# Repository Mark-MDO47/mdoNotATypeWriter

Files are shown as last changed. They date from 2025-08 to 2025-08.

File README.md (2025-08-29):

# mdo NotATypeWriter
My version of the fantastic Adafruit Learning project "Not A Typewriter".

The original is here:
- https://learn.adafruit.com/not-a-typewriter
- Ruiz Brothers and Liz Clark

I am happy to provide Attribution to Adafruit and to the Ruiz Brothers (3D design) and to Liz Clark (author of the code) !

| Original | Mine |
| --- | --- |
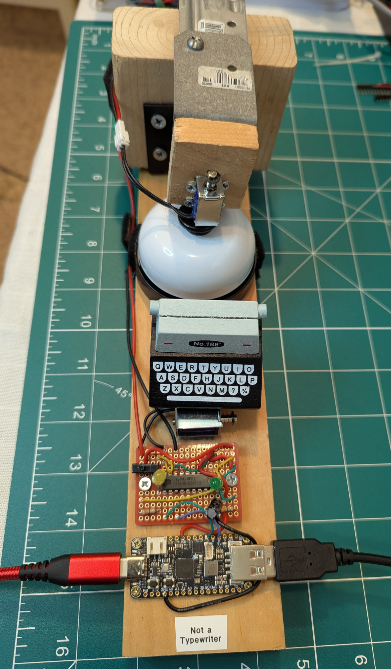
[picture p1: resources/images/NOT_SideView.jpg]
MDO Not A TypewriterFront View
| Original Adafruit Learning Not A Typewriter |  |

**Table Of Contents**
* [Top](#mdo-notatypewriter "Top")
* [Introduction](#introduction "Introduction")
* [Differences from Original Adafruit Learning Not A Typewriter](#differences-from-original-adafruit-learning-not-a-typewriter "Differences from Original Adafruit Learning Not A Typewriter")
* [RP2040 and Dual USB](#rp2040-and-dual-usb "RP2040 and Dual USB")
  * [CircuitPython USB Keyboard Documentation](#circuitpython-usb-keyboard-documentation "CircuitPython USB Keyboard Documentation")
  * [Arduino USB Keyboard Documentation](#arduino-usb-keyboard-documentation "Arduino USB Keyboard Documentation")
* [The Code - Derived from Adafruit Learning](#the-code-\--derived-from-adafruit-learning "The Code - Derived from Adafruit Learning")
* [Schematic](#schematic "Schematic")
* [Assembly](#assembly "Assembly")
* [Parts List](#parts-list "Parts List")
* [License](#license "License")

## Introduction
[Top](#mdo-notatypewriter "Top")<br>
The "Not A Typewriter" project was so great I had to make a copy for myself.

Here is a video of my version in action:
- https://youtube.com/shorts/a_9GTjH4s5s

## Differences from Original Adafruit Learning Not A Typewriter
[Top](#mdo-notatypewriter "Top")<br>
Some parts were unavailable at this time and others I chose to do in a slightly different manner.
- The I2C Solenoid Driver https://www.adafruit.com/product/6318 was not available at the time I ordered
  - ... so I replaced it with a non-I2C version https://www.adafruit.com/product/970
- The original project includes files for a beautiful 3D-printed typewriter/project-box
  - ... I chose to use a "dollhouse" typewriter https://www.amazon.com/dp/B0B86HYR6P and some cardboard boxes and scrap I had on hand

Here is an image of most of the cast of characters for this project.<br>
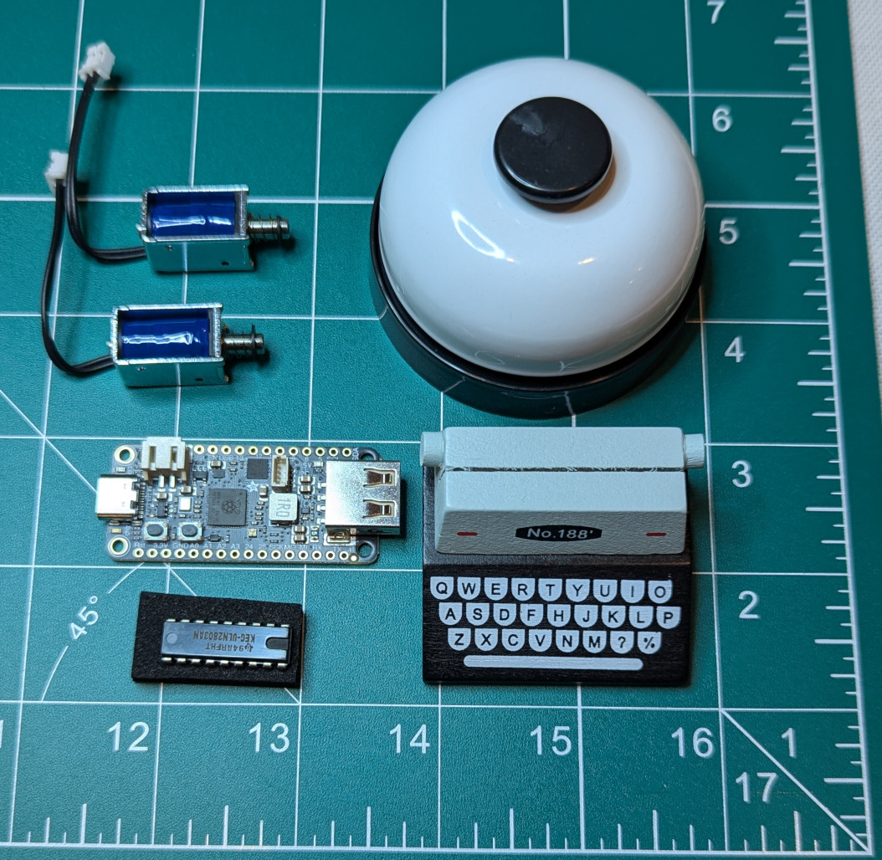
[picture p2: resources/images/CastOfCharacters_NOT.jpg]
My cast of characters for Not A Typewriter


## RP2040 and Dual USB
[Top](#mdo-notatypewriter "Top")<br>
The RP2040 is a new experience for me, as is the use of two USB interfaces. I gather that the "device" USB port is used to program the RP2040 and implemented by its native hardware USB facilities while the "host" USB port is implemented by software bit-banging, requiring one of the two M0 ARM cores of the RP2040 and both PIO peripherals. Still learning about this.
- https://www.adafruit.com/product/5723	https://learn.adafruit.com/adafruit-feather-rp2040-with-usb-type-a-host
- https://github.com/adafruit/Adafruit-Feather-RP2040-USB-Host-PCB/blob/main/Adafruit_Feather_RP2040_USB_Host_PrettyPins.pdf

This area contains information about the dual USB usage.
- https://github.com/adafruit/Adafruit_TinyUSB_Arduino/tree/master/examples/DualRole

Here is a work-in-progress list of things I need to keep in mind regarding this Dual USB technique and the RP2040.

For Arduino-style programming:
- RP2040: "pio_usb.h" must not be included, otherwise pio-usb will be used as host controller

For CircuitPython-style programming:
- nothing yet

### CircuitPython USB Keyboard Documentation
Some useful documentation for reading the keyboard data from the USB-A port
- https://learn.adafruit.com/using-a-keyboard-with-usb-host?view=all
- https://learn.adafruit.com/using-a-keyboard-with-usb-host/circuitpython
- https://learn.adafruit.com/adafruit-feather-rp2040-with-usb-type-a-host/usb-host-device-info-2

Some useful information for relaying keyboard data to the USB-C port and on into the PC
- https://docs.circuitpython.org/projects/hid/en/latest/
- https://docs.circuitpython.org/projects/hid/en/latest/api.html
- https://learn.adafruit.com/circuitpython-essentials/circuitpython-hid-keyboard-and-mouse
- https://learn.adafruit.com/adafruit-circuit-playground-express/circuitpython-hid-keyboard

### Arduino USB Keyboard Documentation
Some useful documentation for reading the keyboard data from the USB-A port
- https://learn.adafruit.com/using-a-keyboard-with-usb-host?view=all
- https://learn.adafruit.com/using-a-keyboard-with-usb-host/arduino
- https://learn.adafruit.com/adafruit-feather-rp2040-with-usb-type-a-host/arduino-ide-setup

## The Code - Derived from Adafruit Learning
[Top](#mdo-notatypewriter "Top")<br>
Here is a link to the area with my version of the code and a description of the changes I made.
- https://github.com/Mark-MDO47/mdoNotATypeWriter/blob/master/code/USB_Host_Not_A_Typewriter/README.md

## Schematic
[Top](#mdo-notatypewriter "Top")<br>
Below is the schematic for my version of the Not A Typewriter project.
- The main difference from the original version is the use of the ULN2803A chip instead of the I2C Solenoid Driver module
  - My favorite explanation of how to use ULN2803A are posts from pcmanbob starting at "Aug 15, 2023 9:13 am": https://forums.raspberrypi.com/viewtopic.php?t=354993
- I chose to use some regular GPIO pins to control the solenoids instead of the ones on the I2C connector
  - Saving the I2C connector in case I have another use for it
- I have some LEDs that flash when the solenoids activate and a switch that disables the solenoids but allows the LEDs to still work. This lets me type quietely when my family is asleep.

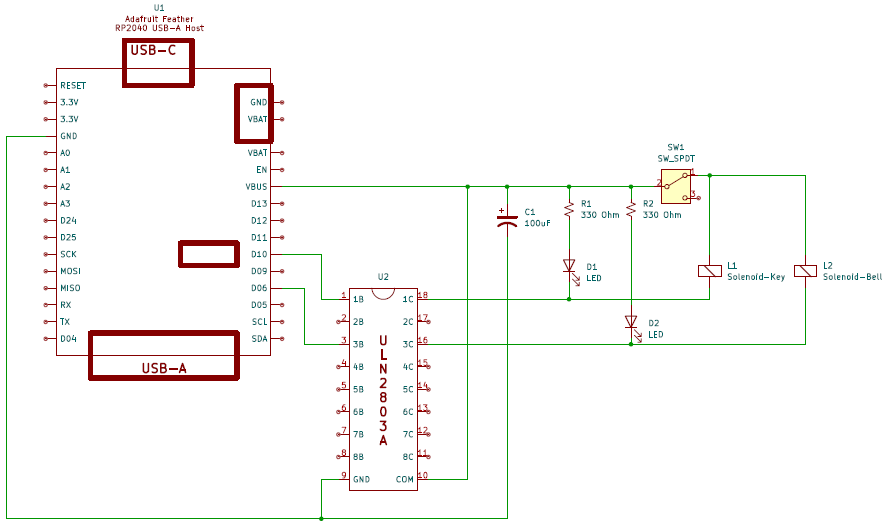
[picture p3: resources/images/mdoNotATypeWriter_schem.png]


## Assembly
[Top](#mdo-notatypewriter "Top")<br>
Below is a conceptual assembly diagram. Most of this is assembled on a perf stripboard; see below.<br>
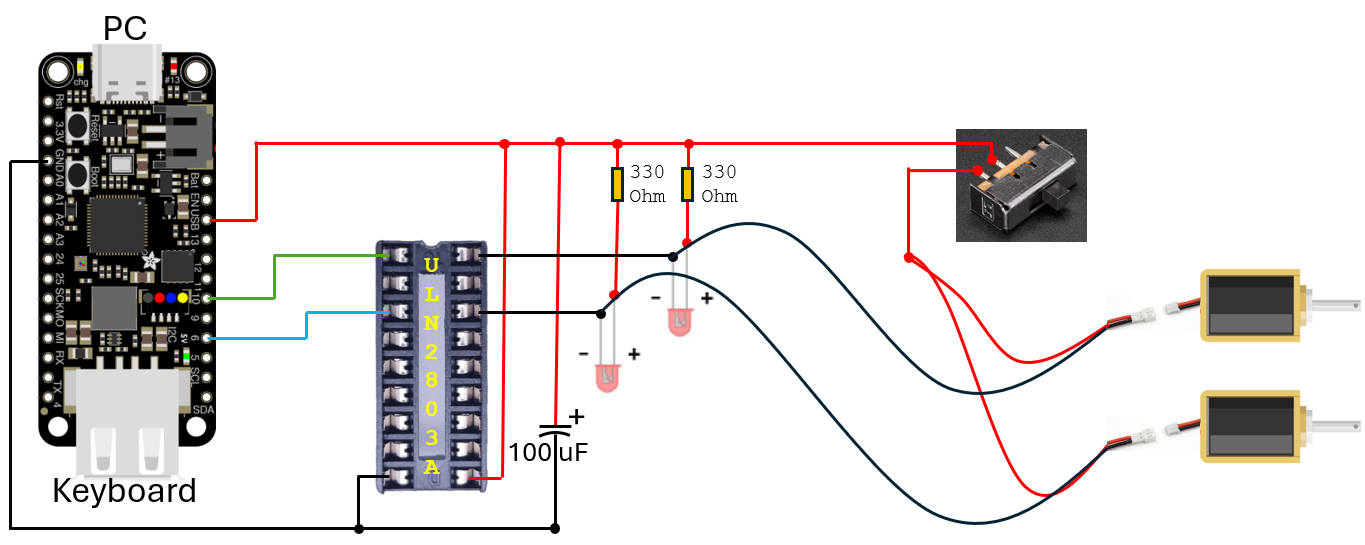
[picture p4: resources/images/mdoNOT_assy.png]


At first I had a circuit mistake: connected ULN2803A COM with GROUND instead of +5V. After spending an unjustifiable amount of time, I corrected it. The following shows a depiction similar to my debugging efforts.
- https://x.com/MakerIO/status/1953442023186305311

With the addition of the LEDs, resistors, and switch it got complicated enough to use a StripBoard for part of the circuit. By not including the Feather RP2040 on the StripBoard I was able to keep the board quite small. Here is an indication of how it is assembled.
- Squares starting with F are connections from the Feather RP2040, SOL from the solenoids, SW a connection to the switch, R and C for resistor and capacitor, L for LED, and W for wire.
- The center dark area is the ULN2803A.

| Image | Connections | Assembled |
| --- | --- | --- |
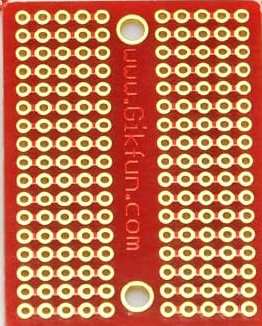
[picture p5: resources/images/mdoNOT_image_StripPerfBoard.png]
StripBoard Picture
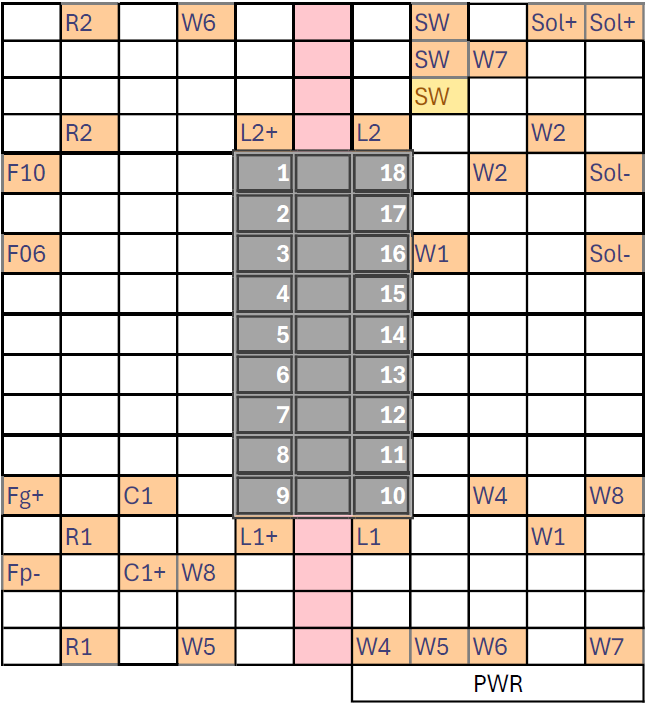
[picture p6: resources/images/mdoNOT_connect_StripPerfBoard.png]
StripBoard Connections
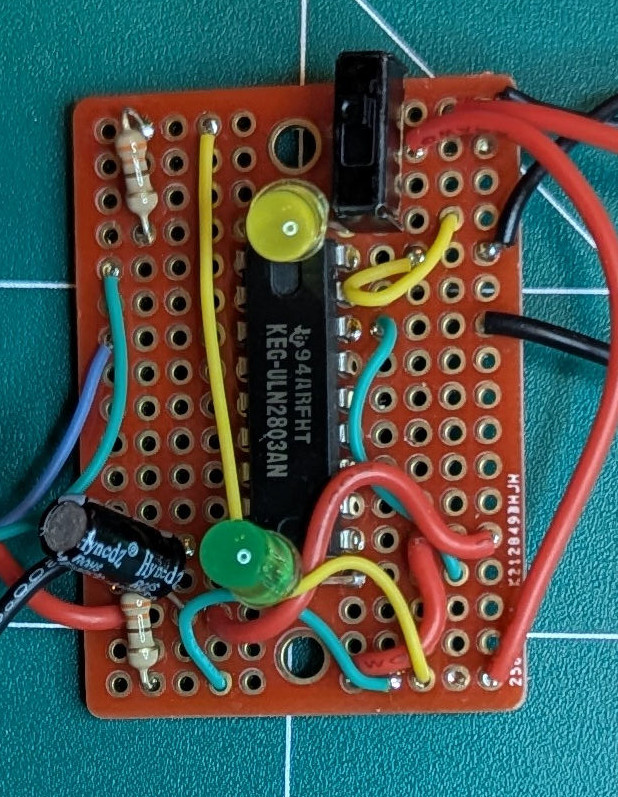
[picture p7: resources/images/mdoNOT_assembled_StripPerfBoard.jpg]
StripBoard Assembled
|  |  |  |

Below is the assembled electronics.<br>

| Top View | Front View |
| --- | --- |
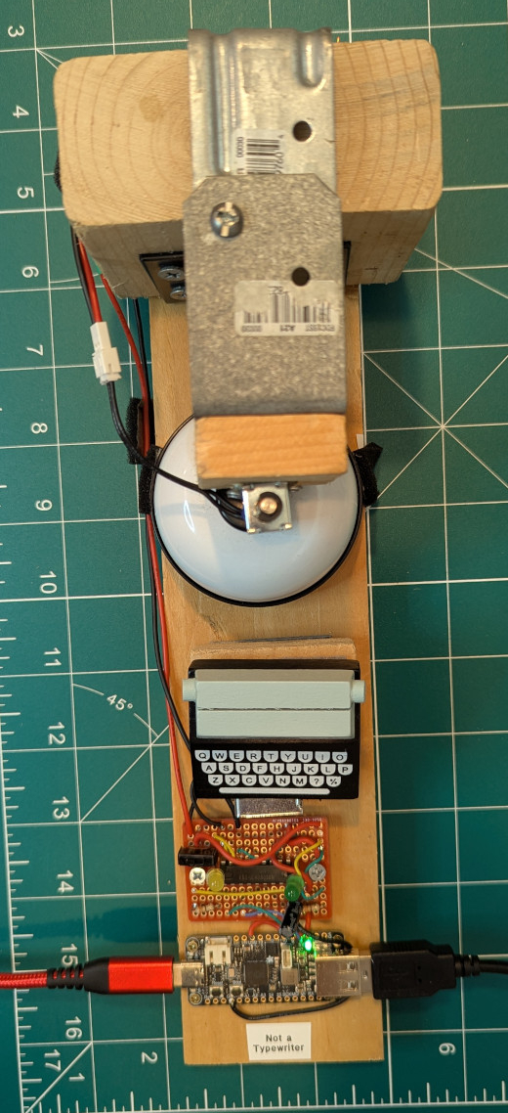
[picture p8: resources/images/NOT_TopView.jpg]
Top View
|  | Front View |

## Parts List
[Top](#mdo-notatypewriter "Top")<br>

| Price (each) | Num | Description | URL or similar |
| --- | --- | --- | --- |
| $17.50 | 1 | Adafruit Feather RP2040 with USB Type A Host | https://www.adafruit.com/product/5723<br>https://learn.adafruit.com/adafruit-feather-rp2040-with-usb-type-a-host<br>https://github.com/adafruit/Adafruit-Feather-RP2040-USB-Host-PCB/blob/main/Adafruit_Feather_RP2040_USB_Host_PrettyPins.pdf |
| $9.60 | 1 | Toyvian Dollhouse Miniature Typewriter Typewriter Mini Office Typewriter Tiny Wooden Typewriter Decor Miniature Antique Typewriter Classic Manual Typewriter Dollhouse Decor Accessories | https://www.amazon.com/dp/B0B86HYR6P |
| $2.50 | 1 | 2 PCS Small Call Bell, 2.56 Inch Service Bell, Ring Bell for Service, Dinner Bell, Counter Bell, Desk Bell | https://www.amazon.com/dp/B0DYDWRYZT |
| $4.00 | 1 | ULN2803: 8 Channel Darlington Driver (Solenoid/Unipolar Stepper) - ULN2803A | https://www.adafruit.com/product/970<br>https://www.openhacks.com/uploadsproductos/uln2803a.pdf<br>https://www.ic-components.com/blog/Your-Guide-to-ULN2803A-Transistor-Array.jsp |
| N/A | 1 | 100uF 16V Electrolytic capacitor | https://www.amazon.com/dp/B081PT78Y5 |
| $5.00 | 2 | Mini Push-Pull Solenoid - 5V | https://www.adafruit.com/product/2776 |
| $0.70 | 1 m/f | 10 PCS (5@M 5@F) Upgraded Tiny Whoop JST-PH 2.0 Male and Female Connector Cable for Battery | https://www.amazon.com/dp/B07NWD5NTN |
| $0.95 | 1 | Breadboard-friendly SPDT Slide Switch | https://www.adafruit.com/product/805 |
| $0.15 | 2 | LED Green Diffused 3mm Round | https://www.digikey.com/en/products/detail/w%C3%BCrth-elektronik/151031VS06000/4489988 |
| $0.10 | 2 | 330-Ohm 1/4 watt through-hole resistors | https://www.digikey.com/en/products/detail/yageo/CFR-25JB-52-330R/1636 |
| $2.00 | 1 | small StripBoard | https://www.amazon.com/dp/B0778G64QZ<br>alt: https://www.amazon.com/dp/B081MSKJJX |
| ??? | * | various angle brackets, scrap wood, screws and bolts | from my parts bin |

## License
[Top](#mdo-notatypewriter "Top")<br>
I am using the MIT license for this project since that is what Adafruit Learning uses.

There may be code included that I have modified from other open sources (such as Arduino, Espressif, SparkFun, Seeed Studio, DFRobot, RandomNerds, etc.). These other sources may possibly be licensed using a different license model. In such a case I will include some notation of this. Typically I will include verbatim the license in the included/modified source code, but alternatively there might be a LICENSE file in the source code area that points out exceptions to the MIT License.

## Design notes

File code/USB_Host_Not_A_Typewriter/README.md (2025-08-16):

# My version of Adafruit Learning USB_Host_Not_A_Typewriter
The "Not A Typewriter" project was so great I had to make a copy for myself.

**Table Of Contents**
* [Top](#my-version-of-adafruit-learning-usb_host_not_a_typewriter "Top")
* [Attributions](#attributions "Attributions")
* [My Modifications](#my-modifications "My Modifications")
* [License](#license "License")

## Attributions
[Top](#my-version-of-adafruit-learning-usb_host_not_a_typewriter "Top")<br>
This code is derived from Adafruit Learning "Not A Typewriter". The original is here:

- https://learn.adafruit.com/not-a-typewriter
- Ruiz Brothers and Liz Clark

I am happy to provide Attribution to Adafruit and to the Ruiz Brothers (3D design) and to Liz Clark (author of the code) !

## My Modifications
[Top](#my-version-of-adafruit-learning-usb_host_not_a_typewriter "Top")<br>
I am using the USB Host version of the code. In this version the keyboard connects to the Feather RP2040 via a "host-mode" USB-A port and keystrokes are forwarded to the "device-mode" USB-C port (and on to the PC) while also affecting the solenoids to give sound effects. See below for an image of the original version of this from Adafruit Learning.<br>
Original Adafruit Learning Not A Typewriter - USB Host

I am using a non-I2C solenoid driver instead of the I2C version that the original code expects.
- https://www.adafruit.com/product/970

This will be my first significant project using CircuitPython, although I have done a fair bit of Python coding on PCs. Fortunately I don't think my changes will require any drastic coding effort.

It appears that the main point of the change will be in the strike_key_solenoid() and ring_bell_solenoid() routines. The rest will just be initializing, tidying up, and perhaps adjusting some of the configuration parameters to my liking.<br>
Here is what the original code looks like.

```Python
def strike_key_solenoid():
    """Activate the key strike solenoid briefly"""
    noid_1.value = True
    time.sleep(SOLENOID_STRIKE_TIME)
    noid_1.value = False

def ring_bell_solenoid():
    """Activate the bell solenoid briefly"""
    noid_2.value = True
    time.sleep(SOLENOID_STRIKE_TIME)
    noid_2.value = False
```

I will need to initialize some I/O pins
- https://cdn-shop.adafruit.com/datasheets/ULN2803A.pdf
- It looks as if connecting the power this way makes HIGH activate the Solenoid.
- It helps me visualize if I think of current flow instead of voltage.

```Python
import digitalio

# I chose to use ordinary GPIO pins, leaving the I2C connector for other uses
noid1_pin = digitalio.DigitalInOut(board.D10)
noid1_pin.direction = digitalio.Direction.OUTPUT
noid1_pin.value = False

noid2_pin = digitalio.DigitalInOut(board.D6)
noid2_pin.direction = digitalio.Direction.OUTPUT
noid2_pin.value = False
```

And then replace the two routines.

```Python
def strike_key_solenoid():
    """Activate the key strike solenoid briefly"""
    noid1_pin.value = True
    time.sleep(SOLENOID_STRIKE_TIME)
    noid1_pin.value = False

def ring_bell_solenoid():
    """Activate the bell solenoid briefly"""
    noid2_pin.value = True
    time.sleep(SOLENOID_STRIKE_TIME)
    noid2_pin.value = False
```

## License
[Top](#my-version-of-adafruit-learning-usb_host_not_a_typewriter "Top")<br>
The original Adafruit Learning code uses the MIT license, so I am allowed to modify it.

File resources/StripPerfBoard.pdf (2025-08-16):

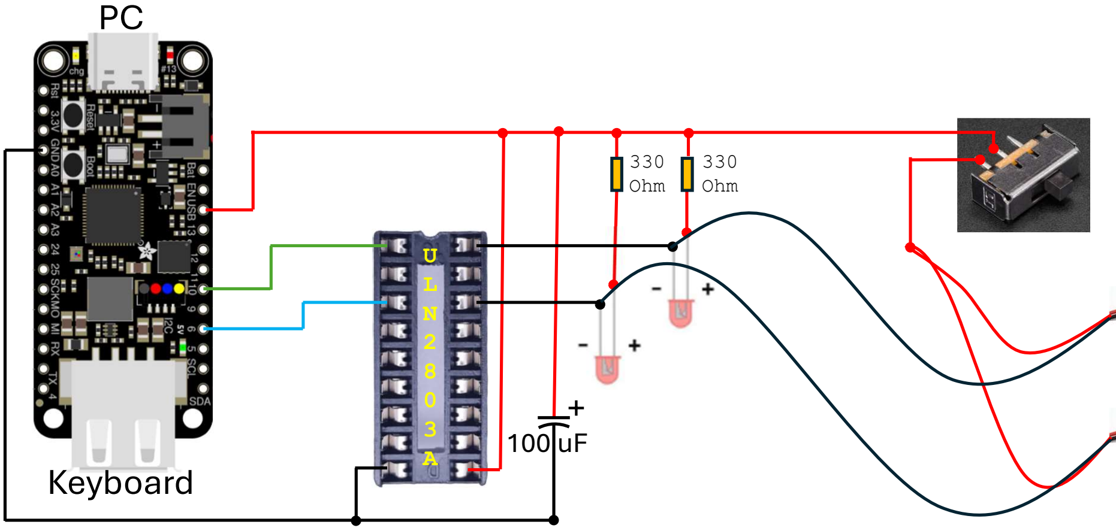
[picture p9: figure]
ULN2803A; Keyboard; 330 Ohm

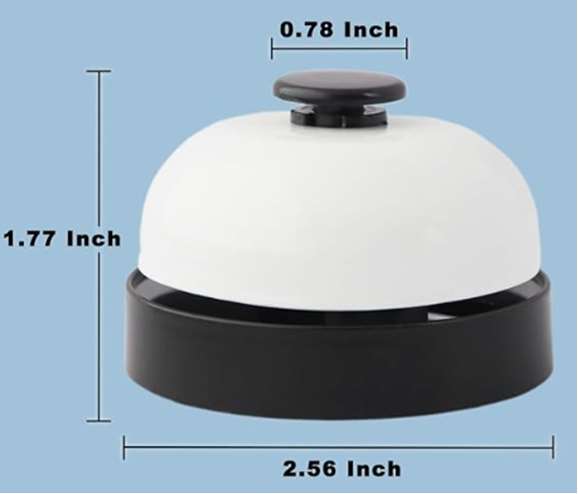
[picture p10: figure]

2x4 = 1.5x3.5x3.6
Plank = 0.75x2.5x23.25
Metal-U = 3.375x2.75down

4.5

Wood 1.5x1.5

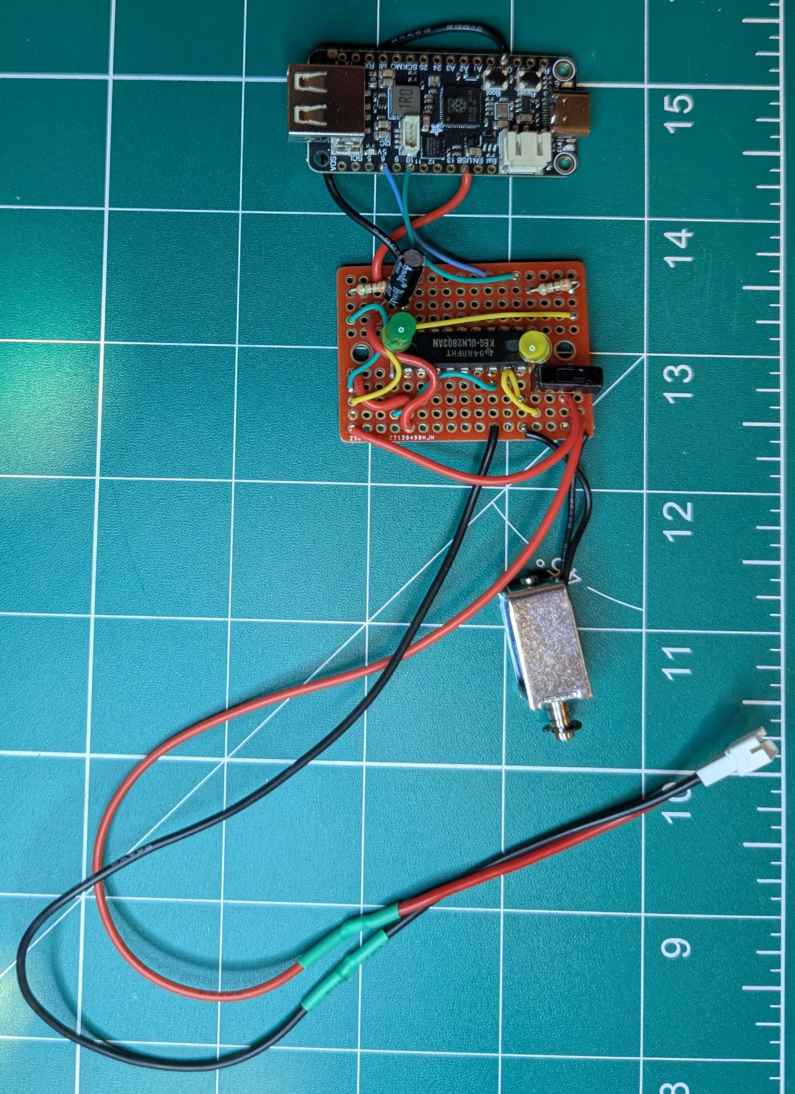
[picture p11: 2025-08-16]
resources/images/mdoNOT_assy_image.jpg

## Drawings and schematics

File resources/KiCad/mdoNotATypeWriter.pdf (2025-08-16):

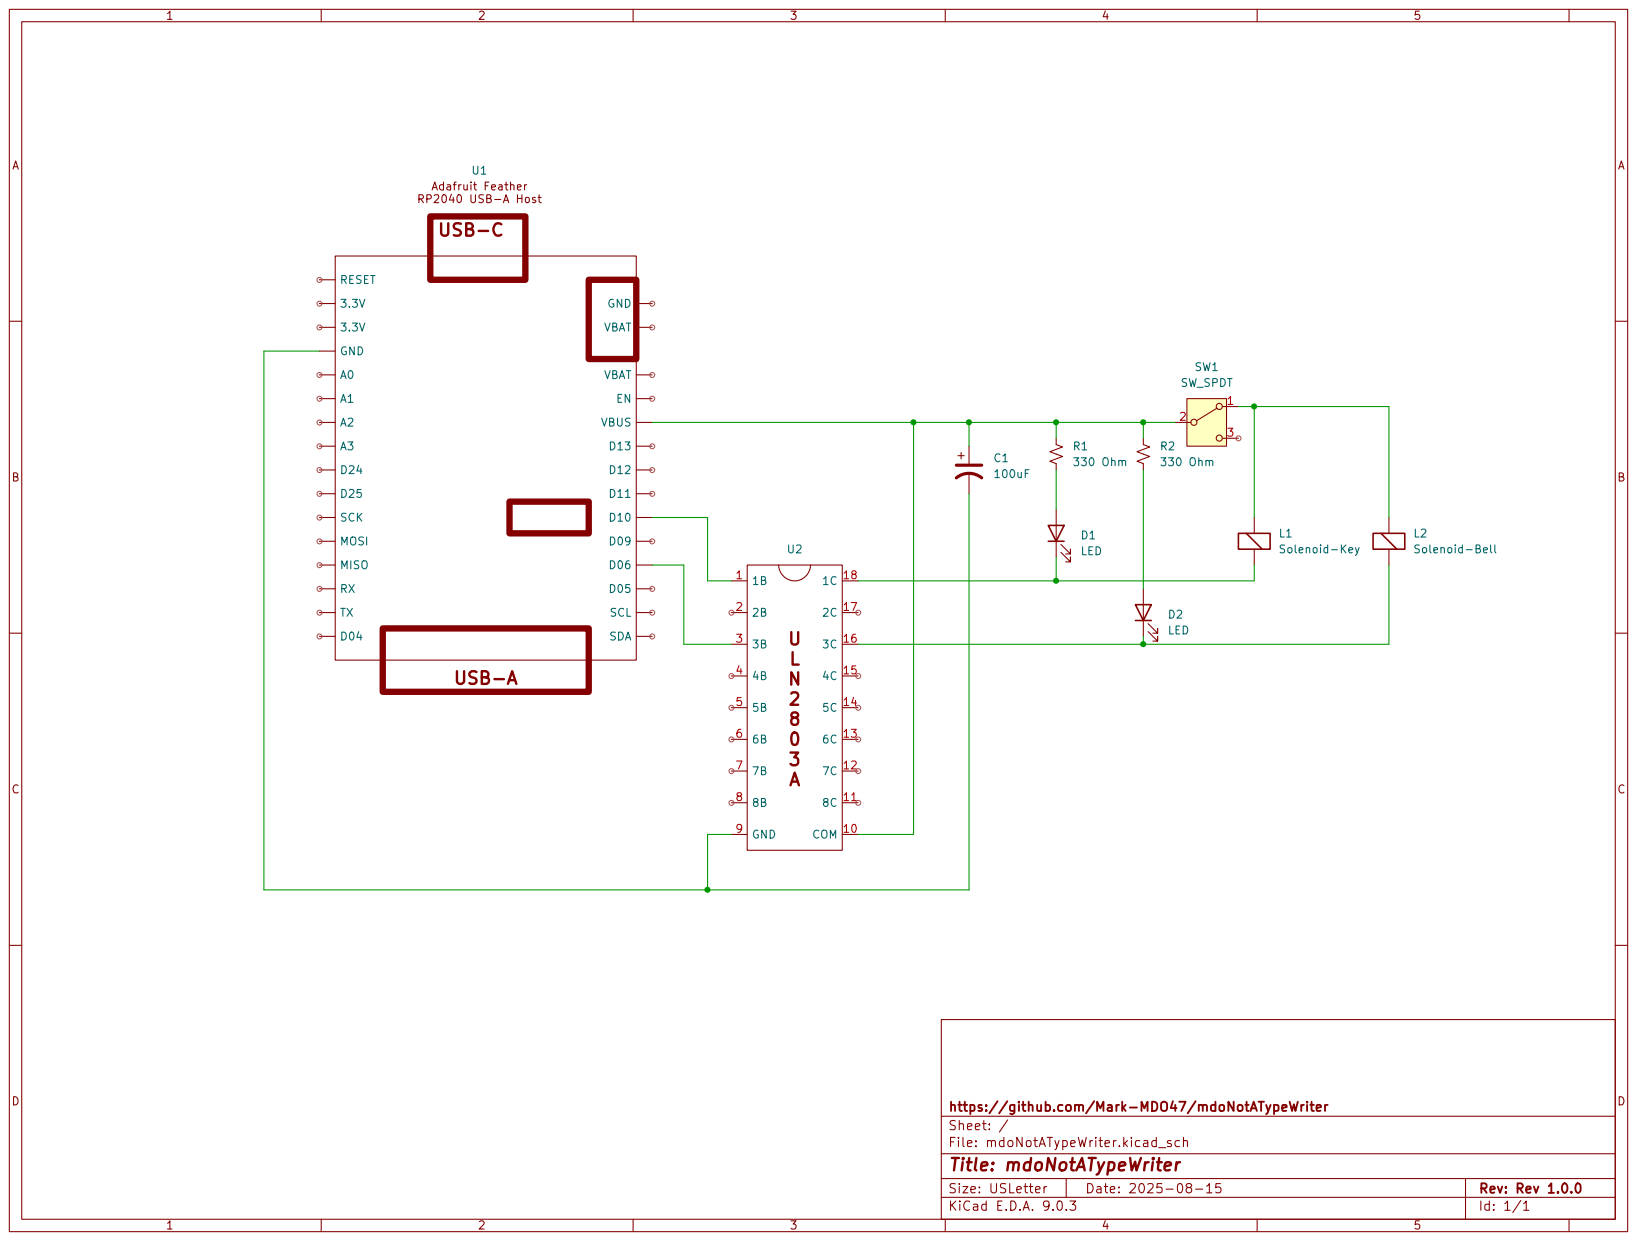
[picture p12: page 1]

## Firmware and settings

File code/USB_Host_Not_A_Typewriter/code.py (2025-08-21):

# SPDX-FileCopyrightText: 2025 Liz Clark for Adafruit Industries
#
# SPDX-License-Identifier: MIT

# https://github.com/Mark-MDO47 2025-08-03 modified for my own build of https://learn.adafruit.com/not-a-typewriter
# https://github.com/Mark-MDO47/mdoNotATypeWriter
# The original code and project description is here:
#    https://learn.adafruit.com/not-a-typewriter
#    Ruiz Brothers and Liz Clark
# Major changes (so far) affecting the code:
#   1 - using https://www.adafruit.com/product/970 (ULN2803A DIP IC)
#          instead of the I2C Solenoid Driver https://www.adafruit.com/product/6318
#   2 - if no keyboard attached to the USB-A port then do a repeating pattern on the
#          solenoids instead of halting
#
# I will use GPIO Digital Output pins instead of the I2C port to control the solenoids.
# This leaves the I2C port and its connector free for other uses
#

import array
import time
import board
# from adafruit_mcp230xx.mcp23017 import MCP23017 # Mark-MDO47 not used in my version
import digitalio # Mark-MDO47 using GPIO digital output for solenoid control

import usb
import adafruit_usb_host_descriptors
import usb_hid
from adafruit_hid.keyboard import Keyboard
from adafruit_hid.keycode import Keycode

# Mark-MDO47 use GPIO Digital Output pins for solenoid control
noid_key_pin = digitalio.DigitalInOut(board.D10)    # Solenoid for KEY press
noid_key_pin.direction = digitalio.Direction.OUTPUT
noid_key_pin.value = False

noid_bell_pin = digitalio.DigitalInOut(board.D6)     # Solenoid for BELL ring
noid_bell_pin.direction = digitalio.Direction.OUTPUT
noid_bell_pin.value = False

# Typewriter configuration
# KEYSTROKE_BELL_INTERVAL = 25  # Ring bell every (basically infinity) keystrokes
SOLENOID_STRIKE_TIME = 0.03   # Duration in seconds for solenoid activation (reduced)
SOLENOID_DELAY = 0.01         # Small delay between solenoid operations (reduced)
ENTER_KEY_CODE = 0x28         # HID code for Enter key
ESCAPE_KEY_CODE = 0x29        # HID code for Escape key
BACKSPACE_KEY_CODE = 0x2A     # HID code for Backspace key
TAB_KEY_CODE = 0x2B           # HID code for Tab key
bell_keys = {ENTER_KEY_CODE, ESCAPE_KEY_CODE, TAB_KEY_CODE}

# Set up USB HID keyboard
hid_keyboard = Keyboard(usb_hid.devices)

# HID to Keycode mapping dictionary
hid_to_keycode = {
    0x04: Keycode.A,
    0x05: Keycode.B,
    0x06: Keycode.C,
    0x07: Keycode.D,
    0x08: Keycode.E,
    0x09: Keycode.F,
    0x0A: Keycode.G,
    0x0B: Keycode.H,
    0x0C: Keycode.I,
    0x0D: Keycode.J,
    0x0E: Keycode.K,
    0x0F: Keycode.L,
    0x10: Keycode.M,
    0x11: Keycode.N,
    0x12: Keycode.O,
    0x13: Keycode.P,
    0x14: Keycode.Q,
    0x15: Keycode.R,
    0x16: Keycode.S,
    0x17: Keycode.T,
    0x18: Keycode.U,
    0x19: Keycode.V,
    0x1A: Keycode.W,
    0x1B: Keycode.X,
    0x1C: Keycode.Y,
    0x1D: Keycode.Z,
    0x1E: Keycode.ONE,
    0x1F: Keycode.TWO,
    0x20: Keycode.THREE,
    0x21: Keycode.FOUR,
    0x22: Keycode.FIVE,
    0x23: Keycode.SIX,
    0x24: Keycode.SEVEN,
    0x25: Keycode.EIGHT,
    0x26: Keycode.NINE,
    0x27: Keycode.ZERO,
    0x28: Keycode.ENTER,
    0x29: Keycode.ESCAPE,
    0x2A: Keycode.BACKSPACE,
    0x2B: Keycode.TAB,
    0x2C: Keycode.SPACE,
    0x2D: Keycode.MINUS,
    0x2E: Keycode.EQUALS,
    0x2F: Keycode.LEFT_BRACKET,
    0x30: Keycode.RIGHT_BRACKET,
    0x31: Keycode.BACKSLASH,
    0x33: Keycode.SEMICOLON,
    0x34: Keycode.QUOTE,
    0x35: Keycode.GRAVE_ACCENT,
    0x36: Keycode.COMMA,
    0x37: Keycode.PERIOD,
    0x38: Keycode.FORWARD_SLASH,
    0x39: Keycode.CAPS_LOCK,
    0x3A: Keycode.F1,
    0x3B: Keycode.F2,
    0x3C: Keycode.F3,
    0x3D: Keycode.F4,
    0x3E: Keycode.F5,
    0x3F: Keycode.F6,
    0x40: Keycode.F7,
    0x41: Keycode.F8,
    0x42: Keycode.F9,
    0x43: Keycode.F10,
    0x44: Keycode.F11,
    0x45: Keycode.F12,
    0x4F: Keycode.RIGHT_ARROW,
    0x50: Keycode.LEFT_ARROW,
    0x51: Keycode.DOWN_ARROW,
    0x52: Keycode.UP_ARROW,
}

# Modifier mapping
modifier_to_keycode = {
    0x01: Keycode.LEFT_CONTROL,
    0x02: Keycode.LEFT_SHIFT,
    0x04: Keycode.LEFT_ALT,
    0x08: Keycode.LEFT_GUI,
    0x10: Keycode.RIGHT_CONTROL,
    0x20: Keycode.RIGHT_SHIFT,
    0x40: Keycode.RIGHT_ALT,
    0x80: Keycode.RIGHT_GUI,
}

#interface index, and endpoint addresses for USB Device instance
kbd_interface_index = None
kbd_endpoint_address = None
keyboard = None

# Mark-MDO47 not used in my version
#
# i2c = board.STEMMA_I2C()
# mcp = MCP23017(i2c)
# noid_2 = mcp.get_pin(0)  # Key strike solenoid
# noid_1 = mcp.get_pin(1)  # Bell solenoid
# noid_1.switch_to_output(value=False)
# noid_2.switch_to_output(value=False)

# Typewriter state tracking
keystroke_count = 0
previous_keys = set()  # Track previously pressed keys to detect new presses
previous_modifiers = 0  # Track modifier state

#interface index, and endpoint addresses for USB Device instance
kbd_interface_index = None
kbd_endpoint_address = None
keyboard = None

# scan for connected USB devices
for device in usb.core.find(find_all=True):
    # check for boot keyboard endpoints on this device
    kbd_interface_index, kbd_endpoint_address = (
        adafruit_usb_host_descriptors.find_boot_keyboard_endpoint(device)
    )
    # if a boot keyboard interface index and endpoint address were found
    if kbd_interface_index is not None and kbd_interface_index is not None:
        keyboard = device

        # detach device from kernel if needed
        if keyboard.is_kernel_driver_active(0):
            keyboard.detach_kernel_driver(0)

        # set the configuration so it can be used
        keyboard.set_configuration()

# if keyboard is None:
#     raise RuntimeError("No boot keyboard endpoint found")

buf = array.array("b", [0] * 8)

# Mark-MDO47 use GPIO pins
def strike_key_solenoid():
    """Activate the key strike solenoid briefly"""
    noid_key_pin.value = True
    time.sleep(SOLENOID_STRIKE_TIME)
    noid_key_pin.value = False

# Mark-MDO47 use GPIO pins
def ring_bell_solenoid():
    """Activate the bell solenoid briefly"""
    noid_bell_pin.value = True
    time.sleep(SOLENOID_STRIKE_TIME)
    noid_bell_pin.value = False

def get_pressed_keys(report_data):
    """Extract currently pressed keys from HID report"""
    pressed_keys = set()

    # Check bytes 2-7 for key codes (up to 6 simultaneous keys)
    for i in range(2, 8):
        k = report_data[i]
        # Skip if no key (0) or error rollover (1)
        if k > 1:
            pressed_keys.add(k)

    return pressed_keys

def print_keyboard_report(report_data):
    # Dictionary for modifier keys (first byte)
    modifier_dict = {
        0x01: "LEFT_CTRL",
        0x02: "LEFT_SHIFT",
        0x04: "LEFT_ALT",
        0x08: "LEFT_GUI",
        0x10: "RIGHT_CTRL",
        0x20: "RIGHT_SHIFT",
        0x40: "RIGHT_ALT",
        0x80: "RIGHT_GUI",
    }

    # Dictionary for key codes (main keys)
    key_dict = {
        0x04: "A",
        0x05: "B",
        0x06: "C",
        0x07: "D",
        0x08: "E",
        0x09: "F",
        0x0A: "G",
        0x0B: "H",
        0x0C: "I",
        0x0D: "J",
        0x0E: "K",
        0x0F: "L",
        0x10: "M",
        0x11: "N",
        0x12: "O",
        0x13: "P",
        0x14: "Q",
        0x15: "R",
        0x16: "S",
        0x17: "T",
        0x18: "U",
        0x19: "V",
        0x1A: "W",
        0x1B: "X",
        0x1C: "Y",
        0x1D: "Z",
        0x1E: "1",
        0x1F: "2",
        0x20: "3",
        0x21: "4",
        0x22: "5",
        0x23: "6",
        0x24: "7",
        0x25: "8",
        0x26: "9",
        0x27: "0",
        0x28: "ENTER",
        0x29: "ESC",
        0x2A: "BACKSPACE",
        0x2B: "TAB",
        0x2C: "SPACE",
        0x2D: "MINUS",
        0x2E: "EQUAL",
        0x2F: "LBRACKET",
        0x30: "RBRACKET",
        0x31: "BACKSLASH",
        0x33: "SEMICOLON",
        0x34: "QUOTE",
        0x35: "GRAVE",
        0x36: "COMMA",
        0x37: "PERIOD",
        0x38: "SLASH",
        0x39: "CAPS_LOCK",
        0x4F: "RIGHT_ARROW",
        0x50: "LEFT_ARROW",
        0x51: "DOWN_ARROW",
        0x52: "UP_ARROW",
    }

    # Add F1-F12 keys to the dictionary
    for i in range(12):
        key_dict[0x3A + i] = f"F{i + 1}"

    # First byte contains modifier keys
    modifiers = report_data[0]

    # Print modifier keys if pressed
    if modifiers > 0:
        print("Modifiers:", end=" ")

        # Check each bit for modifiers and print if pressed
        for b, name in modifier_dict.items():
            if modifiers & b:
                print(name, end=" ")

        print()

    # Bytes 2-7 contain up to 6 key codes (byte 1 is reserved)
    keys_pressed = False

    for i in range(2, 8):
        k = report_data[i]

        # Skip if no key or error rollover
        if k in {0, 1}:
            continue

        if not keys_pressed:
            print("Keys:", end=" ")
            keys_pressed = True

        # Print key name based on dictionary lookup
        if k in key_dict:
            print(key_dict[k], end=" ")
        else:
            # For keys not in the dictionary, print the HID code
            print(f"0x{k:02X}", end=" ")

    if keys_pressed:
        print()
    elif modifiers == 0:
        print("No keys pressed")



# Mark-MDO47 if no keyboard is attached to USB-A, just do test pattern on solenoids
if keyboard is None:
    while True:
        for count in range(2):
            for i in range(9):
                strike_key_solenoid()
                time.sleep(0.2)
            time.sleep(0.6)
            ring_bell_solenoid()
            time.sleep(0.8)
        for count in range(2):
            for i in range(5):
                strike_key_solenoid()
                time.sleep(0.2)
            time.sleep(0.2)
            ring_bell_solenoid()
            time.sleep(0.4)
        for i in range(9):
            strike_key_solenoid()
            time.sleep(0.2)
        time.sleep(0.2)
        ring_bell_solenoid()
        time.sleep(0.4)
        ring_bell_solenoid()
        time.sleep(0.8)


print("USB Typewriter starting...")
# print(f"Bell will ring every {KEYSTROKE_BELL_INTERVAL} keystrokes or when Enter is pressed")

while True:
    # try to read data from the keyboard
    try:
        count = keyboard.read(kbd_endpoint_address, buf, timeout=10)

    # if there is no data it will raise USBTimeoutError
    except usb.core.USBTimeoutError:
        # Nothing to do if there is no data for this keyboard
        continue

    # Get currently pressed keys and modifiers
    current_keys = get_pressed_keys(buf)
    current_modifiers = buf[0]

    # Find newly pressed keys (not in previous scan)
    new_keys = current_keys - previous_keys

    # Find released keys for HID pass-through
    released_keys = previous_keys - current_keys

    # Handle modifier changes
    if current_modifiers != previous_modifiers:
        # Build list of modifier keycodes to press/release
        for bit, keycode in modifier_to_keycode.items():
            if current_modifiers & bit and not previous_modifiers & bit:
                # Modifier newly pressed
                hid_keyboard.press(keycode)
            elif not (current_modifiers & bit) and (previous_modifiers & bit):
                # Modifier released
                hid_keyboard.release(keycode)

    # Release any keys that were let go
    for key in released_keys:
        if key in hid_to_keycode:
            hid_keyboard.release(hid_to_keycode[key])

    # Process each newly pressed key
    for key in new_keys:
        # Increment keystroke counter
        keystroke_count += 1
        # Strike the key solenoid for typewriter effect
        strike_key_solenoid()
        # Pass through the key press via USB HID
        if key in hid_to_keycode:
            hid_keyboard.press(hid_to_keycode[key])

        # Check if special keys were pressed
        if key == ENTER_KEY_CODE:
            ring_bell_solenoid()
            keystroke_count = 0  # Reset counter for new line
        elif key == ESCAPE_KEY_CODE:
            ring_bell_solenoid()
            keystroke_count = 0  # Reset counter
        elif key == TAB_KEY_CODE:
            ring_bell_solenoid()
            keystroke_count = 0  # Reset counter
        elif key == BACKSPACE_KEY_CODE:
            keystroke_count = 0  # Reset counter but no bell
        # elif keystroke_count % KEYSTROKE_BELL_INTERVAL == 0:
            # print(f"\n*** DING! ({keystroke_count} keystrokes) ***\n")
            # ring_bell_solenoid()
    # Special handling for bell keys that are still held
    # check if they were released and re-pressed
    # This handles rapid double-taps where the key might not fully release

    for key in bell_keys:
        if key in current_keys and key in previous_keys and key not in new_keys:
            # Key is being held, check if it was briefly released by looking at the raw state
            # For held keys, we'll check if this is a repeat event
            if len(current_keys) != len(previous_keys) or current_keys != previous_keys:
                # Something changed, might be a repeat
                continue

    # Update previous keys and modifiers for next scan
    previous_keys = current_keys
    previous_modifiers = current_modifiers

    # Still print the keyboard report for debugging
    if new_keys:  # Only print if there are new key presses
        print_keyboard_report(buf)
        print(f"Total keystrokes: {keystroke_count}")

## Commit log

2025-07-31 add schematic
    [Battery_Power.kicad_sch, mdoNotATypeWriter.kicad_pcb, mdoNotATypeWriter.kicad_sch]
2025-08-01 update schematic
    [mdoNotATypeWriter.kicad_sch]
2025-08-07 fix connection to ULN2803A COM
    [mdoNotATypeWriter.kicad_sch]
2025-08-08 add LEDs and switch
    [mdoNotATypeWriter.kicad_sch]
2025-08-10 add resistors for LEDs
    [mdoNotATypeWriter.kicad_sch]
2025-08-10 Use StripPerfBoard, 100 uF cap
    [mdoNotATypeWriter.kicad_sch]
2025-08-15 slide switch
2025-08-16 SPDT switch
    [mdoNotATypeWriter.kicad_sch]
2025-08-17 assembled views
